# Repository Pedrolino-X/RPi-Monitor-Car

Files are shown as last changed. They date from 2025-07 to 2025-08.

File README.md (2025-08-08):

# RPi Monitor Car / 管道巡检车

<p align="center">
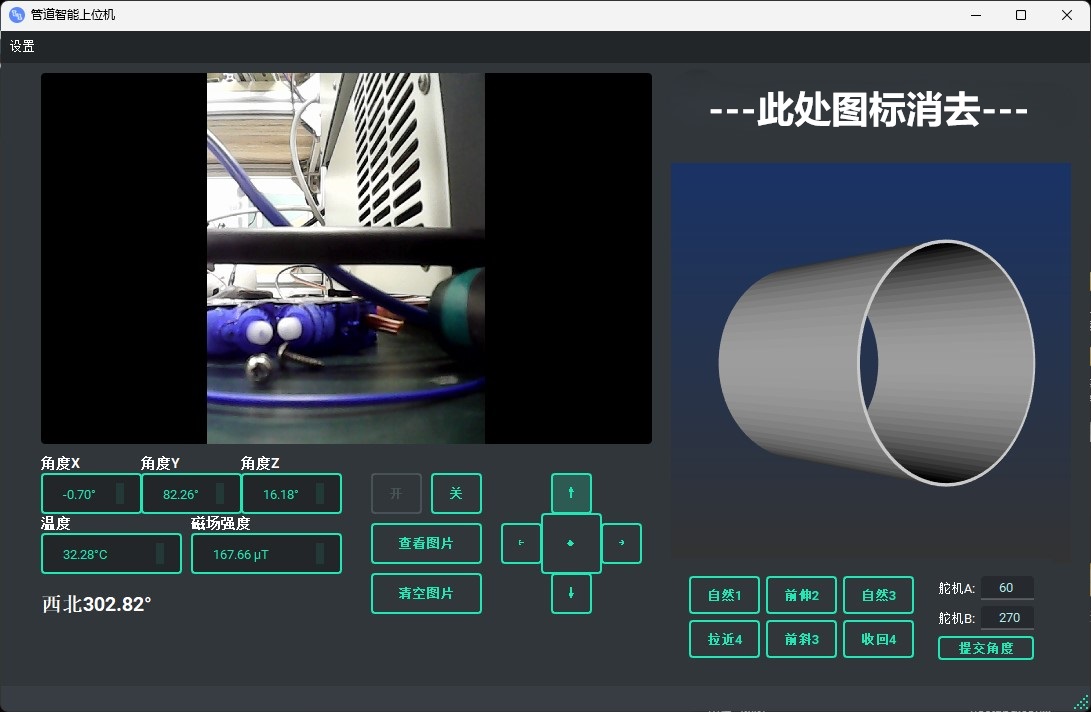
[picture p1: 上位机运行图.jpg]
PC Client Interface
  
</p>

<p align="center">
  
  
  
</p>

A inspection car system based on Raspberry Pi 5 and a PC client, designed for remote visual inspection in narrow environments like pipelines.

一个基于树莓派5和PC上位机的巡检车系统，旨在实现对管道等狭窄环境的远程可视化巡检。

---

## 核心功能 / Core Features

**车载端 (Raspberry Pi):**
- **🚗 运动控制 (Motion Control):** 控制直流电机，实现前进、后退及转向。
- **🧭 姿态感知 (Attitude Sensing):** 集成IMU（JY901S），实时获取并回传车辆的三轴姿态角、温度等数据。
- **📹 视觉采集 (Visual Capture):** 通过摄像头捕捉高清实时视频流，并支持远程拍照。
- **🦾 简易机械臂 (Simple Robotic Arm):** 控制两个舵机，执行预设的抓取或调整动作。
- **📡 无线通信 (Wireless Communication):** 内置TCP服务器，稳定接收PC指令并回传数据。车载端支持AP（热点）模式用于常规操作，以及STA（客户端）模式用于开发调试。

**上位机 (PC Client):**
- **🖥️ 图形化界面 (GUI):** 基于PyQt构建，提供直观的控制与数据显示界面。
- **🕹️ 远程遥控 (Remote Control):** 支持键盘 (W/A/S/D) 和UI按钮两种方式控制小车运动。
- **📊 实时监控 (Real-time Monitoring):**
  - 左侧窗口实时显示摄像头回传的视频流。
  - 中间仪表盘动态可视化展示车辆的俯仰、横滚、偏航角度。
  - 右侧窗口通过VTK加载并显示3D模型。
- **📂 自动文件同步 (Auto File Sync):** 后台服务通过SCP协议自动下载车载端拍摄的照片到本地，方便查看和管理。

---

## 技术栈 / Tech Stack

- **Hardware:** Raspberry Pi 5, JY901S IMU, TB6612FNG Motor Driver, SG90 Servos, Pi Camera
- **Raspberry Pi Software:** Python, OpenCV, RPi.GPIO, Pyserial, Socket
- **PC Client Software:** Python, PyQt5, PyOpenGL, VTK, Paramiko (for SCP)
- **Communication Protocol:** TCP/IP, SCP

---

## 快速开始 / Getting Started

### 1. 树莓派端设置 / Raspberry Pi Setup

1.  **硬件连接 (Hardware Connection):**
    - 根据 `交接文档.md` 内的接线图，连接好电机、舵机、IMU和摄像头。
    - 使用能提供5V/5A的稳定电源为树莓派供电。

2.  **软件部署 (Software Deployment):**
    - **(推荐)** 烧录项目提供的预配置系统镜像 (`.pmfx` 文件，不包含在仓库中)。
    - **(手动)** 或在一个干净的Raspberry Pi OS上，根据 `交接文档.md` 的指南安装所有依赖，并将 `树莓派端代码/` 目录下的文件部署到树莓派。

3.  **启动服务 (Start Service):**
    - 树莓派开机后，系统将默认创建一个名为 `MyPiAP` 的Wi-Fi热点 (密码: `raspberry`)。
    - 服务会自动运行。如果需要手动启动，请在代码目录下执行 `python3 server.py`。

### 2. 上位机端设置 / PC Client Setup

1.  **环境准备 (Environment):**
    - 确保你的PC上安装了 Python 3.7+。
    - 克隆或下载本仓库代码。

2.  **安装依赖 (Install Dependencies):**
    - 打开命令行，进入 `上位机软件代码/` 目录。
    - (推荐) 创建并激活虚拟环境。
    - 运行以下命令安装所有必需的库：
      ```bash
      pip install -r requirements.txt
      ```

3.  **运行程序 (Run Application):**
    - **(开发模式)** 直接运行主程序：
      ```bash
      python main.py
      ```
    - **(可执行文件)** 或直接运行 `上位机软件代码/dist/` 目录下的 `.exe` 文件。

---

## 操作流程 / Usage

1.  **连接网络:** 将你的PC连接到树莓派创建的 `MyPiAP` Wi-Fi网络。
2.  **启动上位机:** 运行PC端的应用程序。
3.  **建立连接:** 在上位机界面点击 **"开"** 按钮。
4.  **开始控制:**
    - 使用 **W, A, S, D** 或界面按钮控制移动。
    - 点击 **"◈"** 按钮或者**P**拍照。
    - 点击 **"查看图片"** 按钮，会自动打开存放同步照片的文件夹。
    - 使用右下角的按钮控制机械臂。
5.  **断开连接:** 点击 **"关"** 按钮结束。

---

## 协议 / License

This project is licensed under the MIT License. See the `LICENSE` file for details.

本项目采用 MIT 协议。详情见 `LICENSE` 文件。

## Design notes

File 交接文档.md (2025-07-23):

# 管道智能巡检车项目交接文档

## 1. 项目概述

本项目是一个基于树莓派5的智能巡检车系统，由**树莓派车载端**和**PC上位机控制端**两部分组成，通过Wi-Fi网络进行无线通信。该系统旨在实现对管道等狭窄环境的远程可视化巡检。

*   **车载端核心功能**:
    *   **运动控制**: 驱动直流电机实现前进、后退、左转、右转。
    *   **姿态感知**: 通过JY901S陀螺仪/IMU传感器实时获取车辆的姿态角、温度、磁场等数据。
    *   **视觉采集**: 使用摄像头捕捉实时视频流。
    *   **机械臂操作**: 控制两个舵机组成的简易机械臂执行预设动作。
    *   **通信服务**: 运行一个TCP服务器，接收上位机指令并回传传感器数据。

*   **上位机核心功能**:
    *   **远程遥控**: 提供图形化界面，通过键盘或UI按钮发送控制指令。
    *   **实时监控**: 显示来自车载摄像头的实时视频流。
    *   **数据可视化**: 以仪表盘形式展示车辆的姿态数据，辅以3D模型呈现。
    *   **文件管理**: 自动同步并管理车载端拍摄的照片。

## 2. 系统架构

```mermaid
graph TD
    subgraph "PC 上位机"
        UI["控制界面 (main.py)"]
        TCP_Client["TCP客户端 (tcpsend.py)"]
        Video_Client["视频流接收 (camera.py)"]
        SCP_Client["文件下载 (SCPDownload.py)"]
        PC_Photos["照片存储 (PC)"]
    end
  
    subgraph "树莓派5巡检车"
        Main_Server["主服务 (server.py)"]
        Hardware_Control["电机/舵机硬件控制 (RPi.GPIO)"]
        Video_Streamer["视频流服务 (OpenCV Port:8081)"]
        IMU_Reader["陀螺仪数据采集 (gyro.py)"]
        TCP_Server["TCP命令服务器 (socket Port:8082)"]
        SSH_Service["系统SSH/SCP服务"]
        RPi_Photos["照片存储 (RPi)"]
    end

    UI -- "发送控制指令 (w, a, s, d, servo...)" --> TCP_Client;
    TCP_Client -- "TCP/IP" --> TCP_Server;
    TCP_Server -- "解析指令" --> Hardware_Control;
  
    Video_Streamer -- "发送视频帧" --> Video_Client;
    Video_Client -- "解码并显示" --> UI;
  
    IMU_Reader -- "获取数据" --> Main_Server;
    Main_Server -- "打包数据" --> TCP_Server;
    TCP_Server -- "回传传感器数据 (angleX, angleY...)" --> UI;
  
    TCP_Server -- "调用拍照函数" --> Video_Streamer;
    Video_Streamer -- "保存照片" --> RPi_Photos;
  
    SCP_Client -- "轮询请求新文件" --> SSH_Service;
    SSH_Service -- "通过SCP传输" --> RPi_Photos;
    RPi_Photos -- "传输到PC" --> SCP_Client;
    SCP_Client -- "保存照片" --> PC_Photos;
```

## 3. 树莓派端 (车载端) 详细部署指南

### 3.1 硬件物料清单 (BOM)

| 类别 | 名称 | 数量 | 备注 |
| :--- | :--- | :--- | :--- |
| **核心** | 树莓派 5 | 1 | |
| | 32GB / 64GB MicroSD 卡（推荐64G） | 1 | |
| | 移动电源 | 1 | 需提供稳定5V/5A供电 |
| **视觉** | 树莓派摄像头模组 | 1 | CSI接口或USB接口均可 |
| **传感** | 维特智能 JY901S 陀螺仪 | 1 | UART通信 |
| **驱动** | TB6612FNG 电机驱动板 (或类似) | 1 | |
| | 直流减速电机 | 2 | |
| | SG90/MG90A 舵机 (推荐MG90A) | 2 | 组成机械臂 |
| **其他** | 杜邦线、车架、轮子等 | 若干 | |

### 3.2 硬件接线配置

**警告：接线前请确保树莓派已断电。所有GPIO引脚编号均基于BCM模式。**

| 组件 | 组件引脚 | 连接至树莓派GPIO引脚 | 功能说明 |
| :--- | :--- | :--- | :--- |
| **电机驱动板** | STBY | 3.3V | 驱动板使能 |
| | PWMA | GPIO 13 (PWM0) | 左轮电机PWM调速 |
| | AIN1 | GPIO 19 | 左轮电机方向控制1 |
| | AIN2 | GPIO 26 | 左轮电机方向控制2 |
| | PWMB | GPIO 16 (PWM0) | 右轮电机PWM调速 |
| | BIN1 | GPIO 20 | 右轮电机方向控制1 |
| | BIN2 | GPIO 21 | 右轮电机方向控制2 |
| | GND | GND | 共地 |
| | VCC/VM | - | 接外部电源正极 (如移动电源12V) |
| **舵机A** | 信号线 (橙色) | GPIO 17 (PWM1) | 舵机A PWM控制 |
| | VCC (红色) | 5V |按照产品使用3.3V/5V |
| | GND (棕色) | GND | 注意共地|
| **舵机B** | 信号线 (橙色) | GPIO 22 | 舵机B PWM控制 |
| | VCC (红色) | 5V | 按照产品使用3.3V/5V|
| | GND (棕色) | GND | 注意共地|
| **JY901S陀螺仪**| VCC | 3.3V | |
| | GND | GND | 注意共地|
| | TX | **GPIO 15 (RXD0)** | 树莓派的接收端 |
| | RX | **GPIO 14 (TXD0)** | 树莓派的发送端 |
| **摄像头** | - | CSI接口 / USB接口 | 视频采集 |

### 3.3 系统镜像部署 (首选方案)

此方案为最快捷的方式，包含了所有配置好的环境和代码。

1.  **下载工具**: 在PC上准备好磁盘镜像烧录工具 (如 `DiskGenius`, `Raspberry Pi Imager` 等)。
2.  **准备镜像**: 找到项目文件中的 `RPiCC_MonitorCar_SystemImage_Final_20250714_Archived.pmfx` (此文件不包含在Git仓库中)。
3.  **烧录镜像**:
    *   使用烧录工具，将 `.pmfx` 镜像文件恢复到 MicroSD 卡。
4.  **启动**: 将烧录好的内存卡插入树莓派5，连接好所有硬件并通电启动。

### 3.4 手动环境搭建 (高级/备用方案)
如果您想从一个全新的、纯净的Raspberry Pi OS系统开始，请按以下步骤操作：

1.  **烧录系统**: 使用 Raspberry Pi Imager 烧录最新的 "Raspberry Pi OS with desktop (64-bit)"。
2.  **基础配置**:
    *   通过外接显示器和键鼠完成首次启动向导。
    *   在终端中，启用 **SSH**, **VNC**, **UART (Serial Port)**, 和 **Legacy Camera Support** (如果使用旧款摄像头)。可通过 `sudo raspi-config` 命令进行设置。
    *   开启UART (Serial Port)时，若提示是否用于 **Serial Console**，请选择“否”。
3.  **安装系统依赖**:
    ```bash
    sudo apt-get update
    sudo apt-get install -y python3-pip python3-opencv libatlas-base-dev
	sudo pip3 install RPi.GPIO --upgrade
    ```
4.  **安装Python库**:
    ```bash
    pip3 install pyserial numpy
    ```
5.  **部署代码**: 将 `树莓派端代码` 目录下的所有文件和子目录，上传到树莓派的某一工作目录，例如 `/home/pi/rpi_server/`。

### 3.5 网络配置与模式切换

系统内置了通过 `nmcli` (NetworkManager命令行工具) 控制的两种网络模式。

#### 3.5.1 AP模式 (默认热点模式)

*   **用途**: 无需外部路由器，方便户外或现场快速部署。
*   **状态**: 系统镜像烧录后首次启动即进入此模式。
*   **网络详情**:
    *   **Wi-Fi名称 (SSID)**: `MyPiAP`
    *   **密码**: `raspberry`
    *   **树莓派IP**: `192.168.12.1`
*   **切换到此模式**:
    ```bash
    # 在树莓派终端执行
    sudo ./start-ap.sh
    ```

#### 3.5.2 STA模式 (Wi-Fi客户端模式)

*   **用途**: 连接到现有Wi-Fi网络，方便远程开发、调试和访问互联网。
*   **配置方法**:
    1.  在AP模式下，使用SSH连接到树莓派 (`ssh pi@192.168.12.1`)。
    2.  在SSH终端中，编辑 `start-wifi.sh` 文件：`nano ./start-wifi.sh`。
    3.  找到 `nmcli device wifi connect ...` 这一行，将其修改为您的Wi-Fi信息。
    4.  执行切换:
        ```bash
        sudo ./start-wifi.sh
        ```
        树莓派会断开AP，连接到您指定的Wi-Fi。您需要到路由器管理页面或使用网络扫描工具查找树莓派的新IP地址。

## 4. 上位机端 (PC控制端) 详细部署指南

### 4.1 直接运行可执行文件 (首选方案)

1.  在Windows电脑上，找到 `上位机软件代码/dist/` 目录。
2.  双击运行 `main.exe` 或 `上位机.exe` 文件即可启动应用程序。无需安装任何额外软件。

### 4.2 开发环境搭建 (用于二次开发)

1.  **安装Python**: 访问 [Python官网](https://www.python.org/downloads/) 下载并安装Python 3.7+ 版本。**安装时务必勾选 "Add Python to PATH"**。
2.  **拷贝代码**: 将 `上位机软件代码` 目录下的所有源文件拷贝到你的项目目录中。
3.  **创建并激活虚拟环境** (强烈推荐):
    ```bash
    # 在项目目录下打开CMD或PowerShell
    python -m venv venv
    .\venv\Scripts\activate
    ```
4.  **安装依赖**:
    ```bash
    pip install -r requirements.txt
    ```
5.  **运行程序**:
    ```bash
    python main.py
    ```

### 4.3 重新打包为.exe文件

如果修改了代码，需要重新生成 `.exe` 文件：
1.  确保已在虚拟环境中。
2.  安装 PyInstaller: `pip install pyinstaller`。
3.  执行打包命令 (使用 `.spec` 文件可以保留如图标、数据文件等配置):
    ```bash
    pyinstaller 上位机.spec
    ```
4.  打包完成后，新的可执行文件会出现在 `dist/` 目录下。

## 5. 完整操作流程 (从零开始)

1.  **树莓派准备**: 按照 **3.2** 接好所有硬件，然后按照 **3.3** 烧录系统镜像并启动树莓派。
2.  **网络连接**: 在PC上搜索Wi-Fi，连接到 `MyPiAP` (密码: `raspberry`)。
3.  **启动上位机**: 在PC上，运行 `dist` 目录下的可执行文件。
4.  **建立通信**: 在上位机界面，点击 **"开"** 按钮。
    *   如果一切正常，视频画面会出现在左侧，中间的数据仪表盘开始显示数据，右侧的3D模型会加载出来。
5.  **进行遥控**:
    *   **移动**: 使用界面上的方向按钮或键盘 **W, A, S, D**。
    *   **拍照**: 点击界面中心的 **"◈"** 按钮。照片会保存在树莓派上，并由后台服务自动同步到PC的 `Camera_Photos` 目录。
    *   **查看照片**: 点击 **"查看图片"** 按钮，会打开上述照片文件夹。
    *   **机械臂**: 使用右下角的预设按钮或在输入框中填入自定义角度后点击"提交角度"来控制舵机。
6.  **结束操作**: 点击 **"关"** 按钮断开连接，然后关闭上位机程序。

## 6. 代码与文件结构详解

### 6.1 树莓派端

| 文件/目录 | 描述 |
| :--- | :--- |
| `server.py` | **核心服务**。监听8081端口提供视频流，监听8082端口处理TCP指令。包含电机、舵机控制逻辑，并周期性调用 `gyro.py` 获取数据。 |
| `gyro.py` | 陀螺仪数据接口。封装了 `JY901S` 库，提供 `get_gyro_data()` 函数。 |
| `Python-WitProtocol/`| 陀螺仪(维特智能)官方Python SDK。 |
| `start-ap.sh` | 切换到AP模式的脚本。 |
| `start-wifi.sh` | 切换到STA模式的脚本。 |
| `enable-autostart.sh`| 启用服务自启动。 |
| `disable-autostart.sh`| 禁用服务自启动。 |

### 6.2 上位机端

| 文件/目录 | 描述 |
| :--- | :--- |
| `main.py` | **主程序入口**。初始化PyQt界面，绑定所有按钮事件，创建并启动各个功能线程。 |
| `UI_camera.py` | 由 `UI_camera.ui` 生成的UI类，**不要手动修改此文件**。 |
| `tcpsend.py` | **TCP客户端**。负责连接到树莓派的8082端口，发送控制指令并接收回传数据。 |
| `camera.py` | **视频流客户端**。连接到树莓派的8081端口，循环接收视频帧数据并解码。 |
| `SCPDownload.py` | **文件同步服务**。通过SSH和SCP协议，定期将树莓派上的新照片下载到本地。 |
| `model1.stl` | **3D模型文件**，由VTK库在界面右侧加载并渲染。 |
| `requirements.txt` | Python依赖列表，是复现开发环境的关键。 |

## 7. 故障排查 (Troubleshooting)

*   **上位机无法连接?**
    1.  确认PC是否已连接到正确的Wi-Fi (`MyPiAP`)。
    2.  在PC的CMD中 `ping 192.168.12.1`，检查网络是否通畅。
    3.  检查PC的防火墙是否阻止了应用程序的网络访问。

*   **视频无画面但能控制?**
    1.  检查树莓派摄像头是否已正确连接并被系统识别。
    2.  SSH登录树莓派，运行 `ls /dev/video*`，看是否有 `video0` 等设备。
    3.  在树莓派终端手动运行 `python3 server.py`，观察是否有关于摄像头或端口8081的报错。

*   **小车无法移动?**
    1.  检查电机驱动板的接线是否正确，特别是**电源和GND**，**共地**非常重要。
    2.  确认移动电源电量充足，能提供足够电流。
    3.  SSH登录树莓派，运行 `server.py` 并观察是否有 `RPi.GPIO` 相关的报错。

*   **陀螺仪无数据?**
    1.  检查JY901S的UART接线（TX到RX，RX到TX）是否正确，**共地**非常重要。
    2.  确认树莓派的UART功能已在 `raspi-config` 中启用。
    3.  手动运行 `server.py`，观察是否有 `pyserial` 或端口 `/dev/ttyAMA0` 相关的报错。

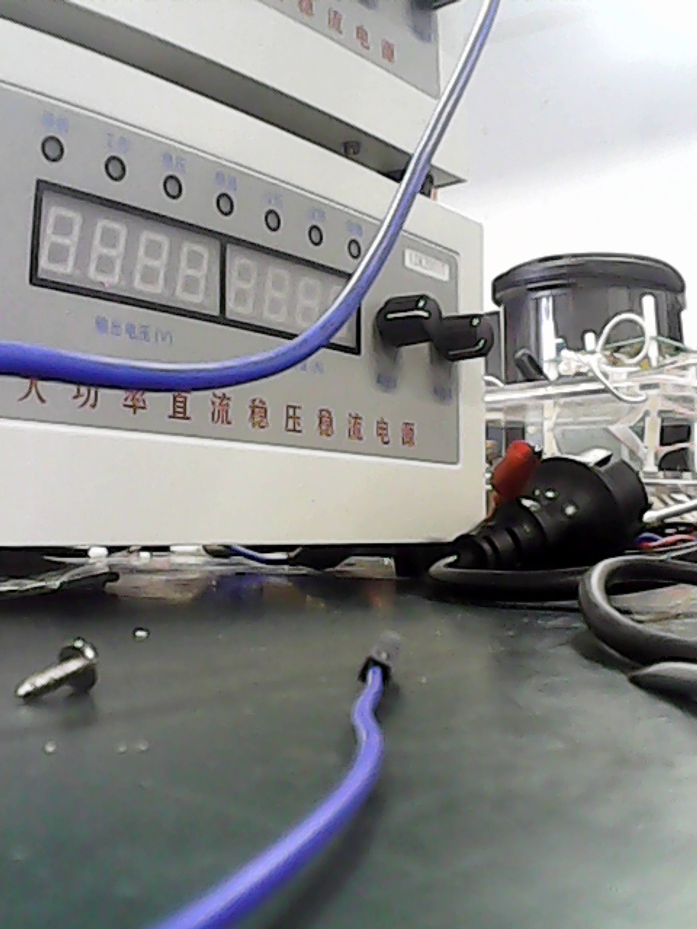
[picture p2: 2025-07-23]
上位机软件代码/Camera_Photos/capture_2025-07-13_23-59-16.jpg

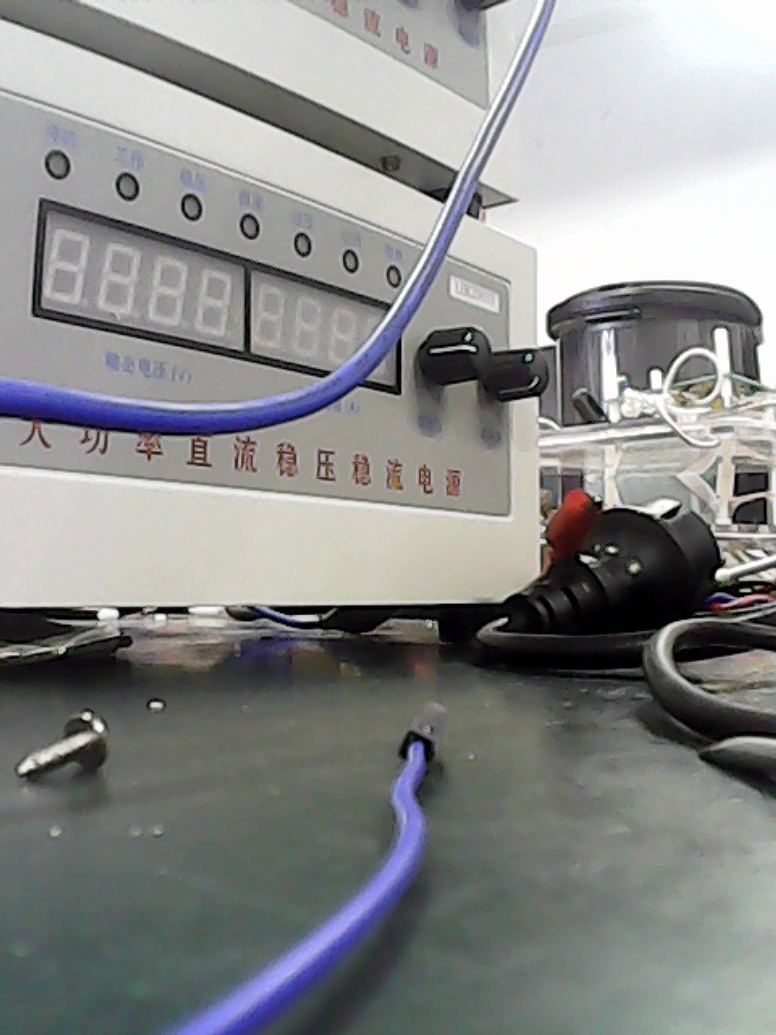
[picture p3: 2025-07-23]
上位机软件代码/Camera_Photos/capture_2025-07-13_23-57-38.jpg

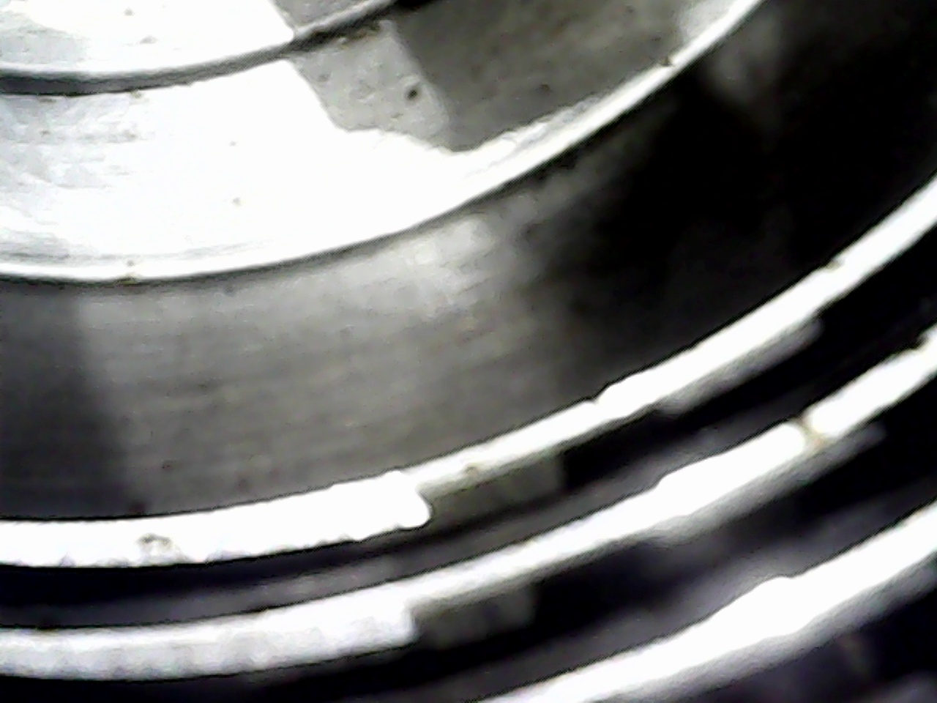
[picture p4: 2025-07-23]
上位机软件代码/Camera_Photos/capture_2024-11-12_17-41-52.jpg

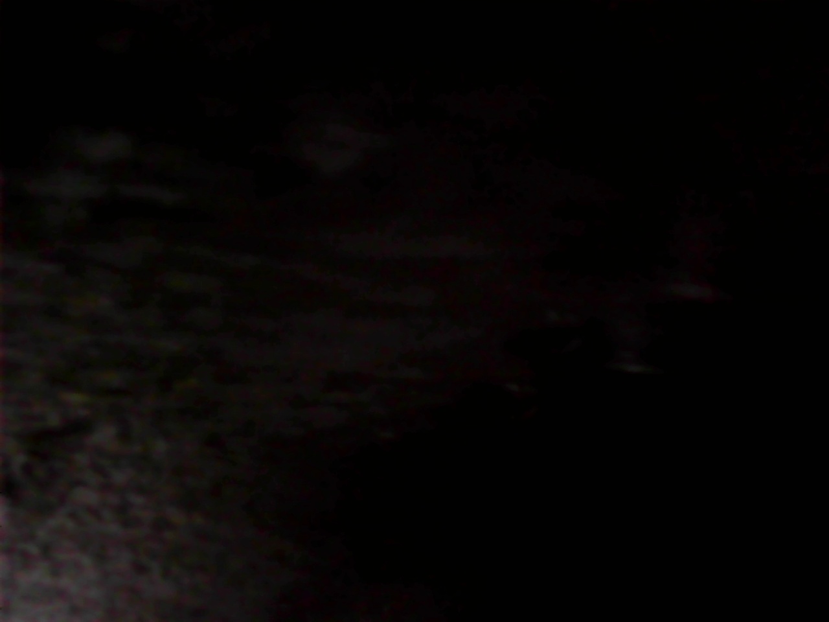
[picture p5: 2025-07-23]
上位机软件代码/Camera_Photos/capture_2024-11-12_17-10-20.jpg

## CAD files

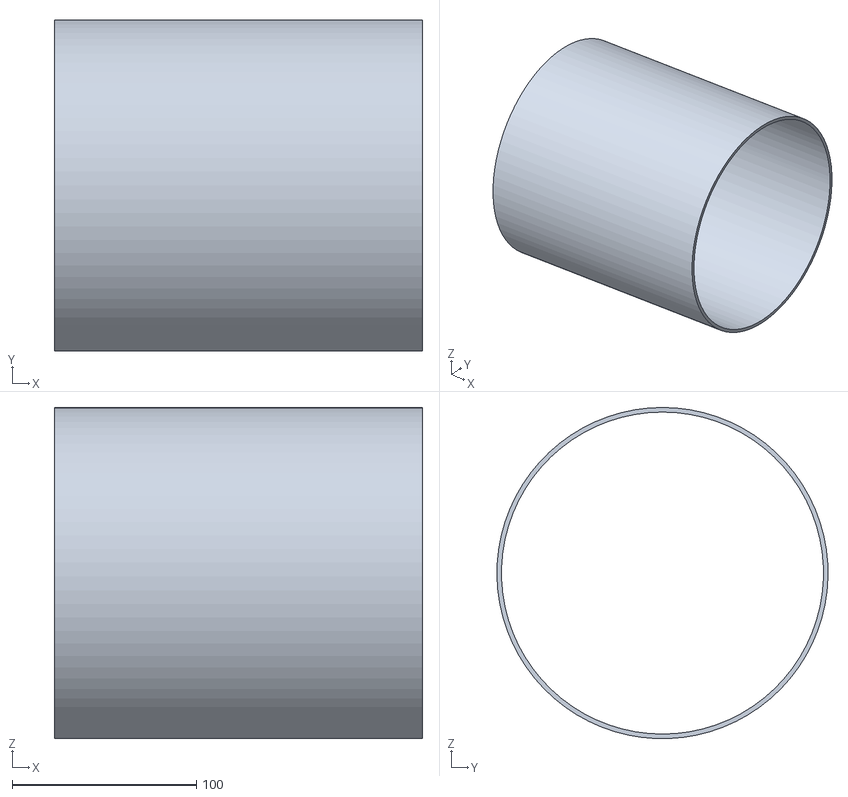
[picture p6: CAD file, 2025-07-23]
上位机软件代码/model1.stl
200.0 x 180.0 x 179.9

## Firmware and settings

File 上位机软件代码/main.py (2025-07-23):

import base64
import shutil
import sys
import os
import threading
import math
from datetime import datetime

from PyQt5.QtWidgets import QMainWindow, QApplication, QMessageBox
from PyQt5.QtGui import QImage, QPixmap
from PyQt5.QtCore import Qt, QThread, pyqtSignal, pyqtSlot
from PyQt5 import uic, QtGui, QtCore
from UI_camera import Ui_MainWindow
from qt_material import apply_stylesheet
import cv2
from lib.share import SI
from camera import NetworkCamera
from tcpsend import TCPClient
from SCPDownload import sync_folder
from memory_pic import logo_ico,saishi_png,gongsi_png
import base64
import vtk
from vtk.qt.QVTKRenderWindowInteractor import QVTKRenderWindowInteractor

def resource_path(relative_path):
    """ Get absolute path to resource, works for dev and for PyInstaller """
    try:
        # PyInstaller creates a temp folder and stores path in _MEIPASS
        base_path = sys._MEIPASS
    except Exception:
        base_path = os.path.abspath(".")

    return os.path.join(base_path, relative_path)

class StlWorker(QtCore.QThread):
    finished = QtCore.pyqtSignal()

    def __init__(self, ren, parent=None):
        super().__init__(parent)
        self.ren = ren

    def run(self):
        stlreader = vtk.vtkSTLReader()
        stlreader.SetFileName(resource_path(".\model1.stl"))
        mapper = vtk.vtkPolyDataMapper()
        mapper.SetInputConnection(stlreader.GetOutputPort())
        mapper.SetScalarVisibility(0)
        actor = vtk.vtkActor()
        actor.SetMapper(mapper)
        self.ren.AddActor(actor)
        self.ren.ResetCamera()
        self.finished.emit()


class IP_Config:
    def __init__(self):
        print("IP配置窗口")
        self.ui = uic.loadUi("ip_config.ui")

class CameraWorker(QThread):
    new_frame = pyqtSignal(object)

    def __init__(self, network_camera, parent=None):
        super().__init__(parent)
        self.network_camera = network_camera
        self.running = False

    def run(self):
        self.running = True
        while self.running:
            if self.network_camera.is_connected():
                try:
                    frame = self.network_camera.get_frame()
                    if frame is not None:
                        self.new_frame.emit(frame)
                except Exception as e:
                    print(f"Exception in CameraWorker: {e}")
            else:
                self.msleep(100)

    def stop(self):
        self.running = False
        self.wait()

class MainWindow(QMainWindow, Ui_MainWindow):
    update_angle_signal = pyqtSignal(dict)  # 定义信号

    def __init__(self, parent=None):
        super(MainWindow, self).__init__(parent)
        # UI界面
        self.camera_worker = None
        self.ctrl_message = None
        self.setupUi(self)
        # self.CAM_NUM = 0
        # self.cap = cv2.VideoCapture()
        self.network_camera = NetworkCamera('192.168.12.1', 8081)
        # self.network_camera = NetworkCamera("http://192.168.4.1:81/stream")
        self.tcp_client = TCPClient('192.168.12.1', 8082)
        self.key_pressed = {}  # 用于跟踪按键状态
        self.button_pressed = set()  # 用于跟踪按钮状态
        self.key_timers = {}  # 用于跟踪按键的定时器
        self.background()

        # --- VTK and STL Model Loading Setup ---
        self.vtkWidget = QVTKRenderWindowInteractor(self.centralwidget)
        self.verticalLayout.addWidget(self.vtkWidget)
        self.ren = vtk.vtkRenderer()
        self.ren.SetBackground(1.0, 1.0, 1.0)
        self.ren.SetBackground2(0.1, 0.2, 0.4)
        self.ren.SetGradientBackground(1)
        self.vtkWidget.GetRenderWindow().AddRenderer(self.ren)
        self.iren = self.vtkWidget.GetRenderWindow().GetInteractor()
        style = vtk.vtkInteractorStyleTrackballCamera()
        self.iren.SetInteractorStyle(style)

        self.stl_worker = StlWorker(self.ren)
        self.stl_worker.finished.connect(self.on_stl_loaded)
        self.stl_worker.start()
        # --- End of VTK Setup ---

        decoded_just = QtCore.QByteArray(base64.b64decode(gongsi_png))
        jpg_just = QtGui.QPixmap()
        jpg_just.loadFromData(decoded_just)
        jpg_just = jpg_just.scaled(
            self.label_just.width()*0.81, self.label_just.height()*0.81, Qt.KeepAspectRatio, Qt.SmoothTransformation)
        self.label_just.setPixmap(jpg_just)

        decoded_shdq = QtCore.QByteArray(base64.b64decode(saishi_png))
        jpg_shdq = QtGui.QPixmap()
        jpg_shdq.loadFromData(decoded_shdq)
        jpg_shdq = jpg_shdq.scaled(
            self.label_shdq.width()*1.0, self.label_shdq.height()*1.0, Qt.KeepAspectRatio, Qt.SmoothTransformation)
        self.label_shdq.setPixmap(jpg_shdq)

        # 为SCP同步创建一个事件
        self.scp_stop_event = threading.Event()
        self.scp_thread = None

        # 启动接收角度数据的线程
        self.start_receiving_data()
        self.update_angle_signal.connect(self.update_display)  # 连接信号和槽
        self.setFixedSize(self.width(), self.height())

    def on_stl_loaded(self):
        self.ren.SetBackground(0.2, 0.2, 0.2)
        camera = self.ren.GetActiveCamera()
        camera.Zoom(1)
        self.iren.SetDesiredUpdateRate(10.0)
        self.vtkWidget.show()
        self.iren.Initialize()

    def ip_set(self):
        SI.mainWin = IP_Config()
        SI.mainWin.ui.show()

    def background(self):
        # 文件选择按钮
        self.camera_on_pushButton.clicked.connect(self.open_connections)
        self.camera_off_pushButton.clicked.connect(self.close_connections)

        self.camera_on_pushButton.setEnabled(True)
        # 初始状态不能关闭摄像头和TCP连接
        self.camera_off_pushButton.setEnabled(False)

        # 目录配置窗口
        self.action_ipconfig.triggered.connect(self.ip_set)

        self.album_pushButton.clicked.connect(self.open_folder)
        self.album_clear_pushButton.clicked.connect(self.clear_album)
        # 按钮控制发送信息
        self.ctrl_up_pushButton.pressed.connect(lambda: self.handle_button_press('w', self.ctrl_up_pushButton))
        self.ctrl_up_pushButton.released.connect(lambda: self.handle_button_release('stop', self.ctrl_up_pushButton))
        self.ctrl_down_pushButton.pressed.connect(lambda: self.handle_button_press('s', self.ctrl_down_pushButton))
        self.ctrl_down_pushButton.released.connect(lambda: self.handle_button_release('stop', self.ctrl_down_pushButton))
        self.ctrl_left_pushButton.pressed.connect(lambda: self.handle_button_press('a', self.ctrl_left_pushButton))
        self.ctrl_left_pushButton.released.connect(lambda: self.handle_button_release('stop', self.ctrl_left_pushButton))
        self.ctrl_right_pushButton.pressed.connect(lambda: self.handle_button_press('d', self.ctrl_right_pushButton))
        self.ctrl_right_pushButton.released.connect(
            lambda: self.handle_button_release('stop', self.ctrl_right_pushButton))
        self.ctrl_shoot_pushButton.released.connect(lambda: self.send_message('p'))
        self.servo_100150_pushButton.pressed.connect(lambda: self.send_message('servoA:100,servoB:150'))
        self.servo_4090_pushButton.pressed.connect(lambda: self.send_message('servoA:40,servoB:90'))
        self.servo_90150_pushButton.pressed.connect(lambda: self.send_message('servoA:40,servoB:90'))
        self.servo_90150_pushButton_2.pressed.connect(lambda: self.send_message('servoM'))
        self.servo_90240_pushButton.pressed.connect(lambda: self.send_message('servoA:90,servoB:240'))
        self.servo_80160_pushButton.pressed.connect(lambda: self.send_message('servoA:80,servoB:160'))
        self.submit_custom_servo_pushButton.clicked.connect(self.send_custom_servo_angles)


    def send_custom_servo_angles(self):
        angle_a = self.servoA_lineEdit.text()
        angle_b = self.servoB_lineEdit.text()
        if angle_a and angle_b:
            try:
                # Validate that inputs are integers
                int(angle_a)
                int(angle_b)
                message = f"servoA:{angle_a},servoB:{angle_b}"
                self.send_message(message)
            except ValueError:
                QMessageBox.warning(self, "输入错误", "角度必须是有效的整数", QMessageBox.Ok)
        else:
            QMessageBox.warning(self, "输入错误", "请输入舵机A和舵机B的角度", QMessageBox.Ok)




    def handle_button_press(self, message, button):
        if button not in self.button_pressed:
            self.button_pressed.add(button)
            self.send_message(message)

    def handle_button_release(self, message, button):
        if button in self.button_pressed:
            self.button_pressed.remove(button)
            self.send_message(message)

    def keyPressEvent(self, event):
        if event.isAutoRepeat():
            return
        key = event.key()
        if key not in self.key_pressed or not self.key_pressed[key]:
            self.key_pressed[key] = True
            self.update_movement()

    def keyReleaseEvent(self, event):
        if event.isAutoRepeat():
            return
        key = event.key()
        if key in self.key_pressed and self.key_pressed[key]:
            self.key_pressed[key] = False
            self.update_movement()

    def capture_photo(self):
        frame = self.network_camera.get_frame()
        if frame is not None:
            # 获取当前日期和时间作为文件名
            timestamp = datetime.now().strftime("%Y%m%d_%H%M%S")
            file_path = f"./Camera_Photos/{timestamp}.jpg"

            # 确保目录存在
            os.makedirs(os.path.dirname(file_path), exist_ok=True)

            # 保存照片
            cv2.imwrite(file_path, frame)
            print(f"照片已保存：{file_path}")
        else:
            print("无法获取视频帧，拍照失败。")

    def clear_photos(self):
        folder_path = "./Camera_Photos"
        if os.path.exists(folder_path):
            # 删除整个文件夹及其内容
            shutil.rmtree(folder_path)
            print("照片已清空。")

            # 重新创建空文件夹
            os.makedirs(folder_path, exist_ok=True)
        else:
            print("照片文件夹不存在，无需清空。")

    def update_movement(self):
        if self.key_pressed.get(Qt.Key_W) and self.key_pressed.get(Qt.Key_A):
            self.send_message('aw')
        elif self.key_pressed.get(Qt.Key_W) and self.key_pressed.get(Qt.Key_D):
            self.send_message('dw')
        elif self.key_pressed.get(Qt.Key_S) and self.key_pressed.get(Qt.Key_A):
            self.send_message('as')
        elif self.key_pressed.get(Qt.Key_S) and self.key_pressed.get(Qt.Key_D):
            self.send_message('ds')
        elif self.key_pressed.get(Qt.Key_W):
            self.send_message('w')
        elif self.key_pressed.get(Qt.Key_S):
            self.send_message('s')
        elif self.key_pressed.get(Qt.Key_A):
            self.send_message('a')
        elif self.key_pressed.get(Qt.Key_D):
            self.send_message('d')
        elif self.key_pressed.get(Qt.Key_P):
            self.send_message('p')
        elif self.key_pressed.get(Qt.Key_Q):
            self.send_message('q')
        elif self.key_pressed.get(Qt.Key_J):
            self.send_message('servoA:130,servoB:130')
        elif self.key_pressed.get(Qt.Key_K):
            self.send_message('servoA:40,servoB:40')
        else:
            self.send_message('stop')

    def open_folder(self):
        folder_path = r'.\Camera_Photos'  # 固定文件夹路径
        os.startfile(folder_path)

    def clear_album(self):
        try:
            # 发送 "clear" 的 TCP 消息
            self.send_message('clear')

            # 删除 .\Camera_Photos 文件夹下的所有文件
            folder_path = r'.\Camera_Photos'
            for filename in os.listdir(folder_path):
                file_path = os.path.join(folder_path, filename)
                if os.path.isfile(file_path):
                    os.remove(file_path)
            print("Album cleared and 'clear' message sent.")
        except Exception as e:
            print(f"Error clearing album: {str(e)}")
            QMessageBox.information(self, "错误", str(e), QMessageBox.Ok)

    # 打开相机和TCP连接
    def open_connections(self):

        try:
            self.network_camera.connect()
            self.tcp_client.connect()
            if not self.network_camera.is_connected():
                QMessageBox.information(self, "警告", "无法连接到网络摄像头", QMessageBox.Ok)
            elif not self.tcp_client.is_connected():
                QMessageBox.information(self, "警告", "无法连接到TCP服务器", QMessageBox.Ok)
            else:
                self.textBrowser_angleX.setText(f"-0.70°")
                self.textBrowser_angleY.setText(f"82.26°")
                self.textBrowser_angleZ.setText(f"16.18°")
                self.textBrowser_temperature.setText(f"32.28°C")
                self.textBrowser_magneticfield.setText(f"167.66 µT")
                self.label_direction.setText(f"西北302.82° ")
                # 幕布可以播放
                self.label.setEnabled(True)
                # 打开摄像头按钮不能点击
                self.camera_on_pushButton.setEnabled(False)
                # 关闭摄像头按钮可以点击
                self.camera_off_pushButton.setEnabled(True)
                
                self.camera_worker = CameraWorker(self.network_camera)
                self.camera_worker.new_frame.connect(self.update_camera_feed)
                self.camera_worker.start()

                self.send_message('servoA:30,servoB:30')
                print("Connections opened!")
                self.start_scp_sync()  # Start SCP sync when connections are open
                self.start_receiving_data()  # 启动接收数据的线程
        except Exception as e:
            QMessageBox.information(self, "错误", str(e), QMessageBox.Ok)

    # 关闭相机和TCP连接
    def close_connections(self):
        if self.camera_worker:
            self.camera_worker.stop()
        
        # Stop the SCP sync thread
        if self.scp_thread and self.scp_thread.is_alive():
            self.scp_stop_event.set()
            self.scp_thread.join(timeout=2) # Wait for the thread to finish

        self.label.setEnabled(False)
        self.network_camera.disconnect()
        self.tcp_client.close()
        self.camera_on_pushButton.setEnabled(True)
        self.camera_off_pushButton.setEnabled(False)
        self.label_direction.setText(f"等待连接... ")
        print("Connections closed!")

    # 发送消息
    def send_message(self, content=None):
        if self.tcp_client.is_connected():
            try:
                msg = content  # 按钮触发用于输入消息
                if msg:
                    print(f"Sending message: {msg}")  # 调试信息
                    threading.Thread(target=self.tcp_client.send_message, args=(msg,)).start()
            except Exception as e:
                print(f"Error sending message: {str(e)}")  # 调试信息
                QMessageBox.information(self, "错误", str(e), QMessageBox.Ok)
        else:
            print("TCP connection is not open.")  # 调试信息
            # QMessageBox.information(self, "警告", "TCP连接未打开", QMessageBox.Ok)

    @pyqtSlot(object)
    def update_camera_feed(self, frame):
        try:
            cur_frame = cv2.cvtColor(frame, cv2.COLOR_BGR2RGB)
            height, width = cur_frame.shape[:2]
            pixmap = QImage(cur_frame, width, height, QImage.Format_RGB888)
            pixmap = QPixmap.fromImage(pixmap)
            ratio = max(width / self.label.width(), height / self.label.height())
            pixmap.setDevicePixelRatio(ratio)
            self.label.setAlignment(Qt.AlignCenter)
            self.label.setPixmap(pixmap)
        except Exception as e:
            print(f"Exception occurred while updating camera feed: {str(e)}")


    # 启动SCP同步线程
    def start_scp_sync(self):
        if self.scp_thread and self.scp_thread.is_alive():
            print("SCP thread is already running.")
            return

        self.scp_stop_event.clear()
        self.scp_thread = threading.Thread(
            target=sync_folder,
            args=(
                "/home/user0000/Desktop/Camera_Photos",  # 服务器上的文件夹路径
                ".\Camera_Photos",  # 本地文件夹路径
                '192.168.12.1',  # 服务器IP
                22,  # SSH端口号
                'user0000',  # SSH用户名
                '0000',  # SSH密码
                1,  # 同步间隔时间（秒）
                self.scp_stop_event # Pass the event to the function
            )
        )
        self.scp_thread.daemon = True
        self.scp_thread.start()
        print("SCP sync thread started.")

    # 启动接收角度数据的线程
    def start_receiving_data(self):
        if self.tcp_client.is_connected():
            receiving_thread = threading.Thread(target=self.receive_data)
            receiving_thread.daemon = True
            receiving_thread.start()

    # 接收并解析数据
    def receive_data(self):
        while self.tcp_client.is_connected():
            try:
                data = self.tcp_client.receive_data()
                if data:
                    # print(data)
                    datasets = self.parse_data(data)
                    if datasets:
                        print(
                            f"angleX: {datasets['angleX']}, angleY: {datasets['angleY']}, angleZ: {datasets['angleZ']}")
                        #self.update_angle_signal.emit(datasets)  # 发射信号
            except Exception as e:
                print(f"Error receiving data: {str(e)}")

    # 解析数据
    def parse_data(self, data):
        try:
            parts = data.split(',')
            datasets = {
                'angleX': float(parts[0].split(':')[1]),
                'angleY': float(parts[1].split(':')[1]),
                'angleZ': float(parts[2].split(':')[1]),
                'temperature': float(parts[3].split(':')[1]),
                'magX': float(parts[4].split(':')[1]),
                'magY': float(parts[5].split(':')[1]),
                'magZ': float(parts[6].split(':')[1])
            }
            return datasets
        except (IndexError, ValueError) as e:
            print(f"Error parsing data: {str(e)}")
            return None

    # 更新显示框
    @pyqtSlot(dict)
    def update_display(self, datasets):
        self.textBrowser_angleX.setText(f"{datasets['angleX']:.2f}°")
        self.textBrowser_angleY.setText(f"{datasets['angleY']:.2f}°")
        self.textBrowser_angleZ.setText(f"{datasets['angleZ']:.2f}°")
        self.textBrowser_temperature.setText(f"{datasets['temperature']:.2f}°C")

        # 计算磁场强度
        magX, magY, magZ = datasets['magX'], datasets['magY'], datasets['magZ']
        mag_strength = math.sqrt(magX ** 2 + magY ** 2 + magZ ** 2)
        self.textBrowser_magneticfield.setText(f"{mag_strength/100:.2f} µT")

        # 计算方向
        angleZ = datasets['angleZ']
        if angleZ < 0:
            angleZ += 360
        angleZ = 359 - angleZ
        directions = [
            (22, "北"), (67, "东北"), (112, "东"),
            (157, "东南"), (202, "南"), (247, "西南"),
            (292, "西"), (337, "西北"), (360, "北")
        ]
        direction_str = next(d for deg, d in directions if angleZ <= deg)
        self.label_direction.setText(f"{direction_str}  {angleZ:.2f}° ")


if __name__ == '__main__':
    QApplication.setHighDpiScaleFactorRoundingPolicy(Qt.HighDpiScaleFactorRoundingPolicy.PassThrough)
    QApplication.setAttribute(Qt.AA_EnableHighDpiScaling)
    QApplication.setAttribute(Qt.AA_UseHighDpiPixmaps)
    app = QApplication(sys.argv)
    main = MainWindow()
    apply_stylesheet(app, theme='dark_teal.xml')

    #方法三：把图片转化为base64
    Logo = QtGui.QPixmap()
    Logo.loadFromData(base64.b64decode(logo_ico))
    icon = QtGui.QIcon()
    icon.addPixmap(Logo, QtGui.QIcon.Normal, QtGui.QIcon.Off)
    main.setWindowIcon(icon)

    main.show()
    sys.exit(app.exec_())

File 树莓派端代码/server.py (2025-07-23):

import socket
import threading
import time
import os
import RPi.GPIO as GPIO
import cv2
import struct
import random
from gyro import get_gyro_data

# --- Motor Control ---
STBY = 27
PWMA = 13
AIN1 = 19
AIN2 = 26
PWMB = 16
BIN1 = 20
BIN2 = 21
hz = 500
speed = 0

def setup_motors():
    GPIO.setmode(GPIO.BCM)
    GPIO.setwarnings(False)
    GPIO.setup(PWMA, GPIO.OUT)
    GPIO.setup(AIN1, GPIO.OUT)
    GPIO.setup(AIN2, GPIO.OUT)
    GPIO.setup(PWMB, GPIO.OUT)
    GPIO.setup(BIN1, GPIO.OUT)
    GPIO.setup(BIN2, GPIO.OUT)
    GPIO.setup(STBY, GPIO.OUT)
    global pwma, pwmb
    pwma = GPIO.PWM(PWMA, hz)
    pwmb = GPIO.PWM(PWMB, hz)
    pwma.start(speed)
    pwmb.start(speed)
    GPIO.output(STBY, True)

def move_forward():
    GPIO.output(AIN1, False)
    GPIO.output(AIN2, True)
    pwma.ChangeDutyCycle(85)
    GPIO.output(BIN1, False)
    GPIO.output(BIN2, True)
    pwmb.ChangeDutyCycle(80)

def move_backward():
    GPIO.output(AIN1, True)
    GPIO.output(AIN2, False)
    pwma.ChangeDutyCycle(85)
    GPIO.output(BIN1, True)
    GPIO.output(BIN2, False)
    pwmb.ChangeDutyCycle(80)

def turn_left():
    GPIO.output(AIN1, False)
    GPIO.output(AIN2, True)
    pwma.ChangeDutyCycle(85)
    GPIO.output(BIN1, True)
    GPIO.output(BIN2, False)
    pwmb.ChangeDutyCycle(80)

def turn_right():
    GPIO.output(AIN1, True)
    GPIO.output(AIN2, False)
    pwma.ChangeDutyCycle(85)
    GPIO.output(BIN1, False)
    GPIO.output(BIN2, True)
    pwmb.ChangeDutyCycle(80)

def stop_movement():
    pwma.ChangeDutyCycle(0)
    pwmb.ChangeDutyCycle(0)

# --- Servo Control ---
servoA_pin = 17
servoB_pin = 22

def setup_servos():
    GPIO.setup(servoA_pin, GPIO.OUT, initial=False)
    GPIO.setup(servoB_pin, GPIO.OUT, initial=False)
    global sA, sB
    sA = GPIO.PWM(servoA_pin, 50)
    sB = GPIO.PWM(servoB_pin, 50)
    sA.start(0)
    sB.start(0)

def set_servo_angle(servo, angle):
    duty_cycle = 2.5 + angle / 180.0 * 10
    servo.ChangeDutyCycle(duty_cycle)
    time.sleep(0.1)
    servo.ChangeDutyCycle(0)



# --- Camera ---
class VideoStreamer:
    def __init__(self, host, port):
        self.host = host
        self.port = port
        self.server_socket = socket.socket(socket.AF_INET, socket.SOCK_STREAM)
        self.clients = []
        self.lock = threading.Lock()
        self.camera = cv2.VideoCapture(0)

    def start(self):
        self.server_socket.setsockopt(socket.SOL_SOCKET, socket.SO_REUSEADDR, 1)
        self.server_socket.bind((self.host, self.port))
        self.server_socket.listen(5)
        print(f"Video streamer listening on {self.host}:{self.port}")
        accept_thread = threading.Thread(target=self.accept_clients)
        accept_thread.daemon = True
        accept_thread.start()

    def accept_clients(self):
        while True:
            client_socket, address = self.server_socket.accept()
            print(f"Video client connected from {address}")
            with self.lock:
                self.clients.append(client_socket)
            stream_thread = threading.Thread(target=self.stream_video, args=(client_socket,))
            stream_thread.daemon = True
            stream_thread.start()

    def stream_video(self, client_socket):
        try:
            while True:
                ret, frame = self.camera.read()
                if not ret:
                    break
                frame = cv2.rotate(frame, cv2.ROTATE_90_CLOCKWISE)
                _, encoded_frame = cv2.imencode('.jpg', frame)
                frame_data = encoded_frame.tobytes()
                frame_size = struct.pack("!L", len(frame_data))
                client_socket.sendall(frame_size + frame_data)
                time.sleep(0.03) # Limit frame rate
        except (BrokenPipeError, ConnectionResetError):
            print("Video client disconnected.")
        finally:
            with self.lock:
                self.clients.remove(client_socket)
            client_socket.close()

    def capture_photo(self, path):
        ret, frame = self.camera.read()
        if ret:
            frame = cv2.rotate(frame, cv2.ROTATE_90_CLOCKWISE)
            cv2.imwrite(path, frame)
            print(f"Photo saved to {path}")

# --- Main Server ---
class CommandServer:
    def __init__(self, host, port, video_streamer):
        self.host = host
        self.port = port
        self.server_socket = socket.socket(socket.AF_INET, socket.SOCK_STREAM)
        self.clients = []
        self.lock = threading.Lock()
        self.video_streamer = video_streamer
        self.photo_dir = os.path.expanduser("~/Desktop/Camera_Photos")
        if not os.path.exists(self.photo_dir):
            os.makedirs(self.photo_dir)

    def handle_client(self, client_socket, address):
        print(f"Command client connected from {address}")
        with self.lock:
            self.clients.append(client_socket)

        try:
            while True:
                data = client_socket.recv(1024).decode('utf-8')
                if not data:
                    break
                print(f"Received command from {address}: {data}")
                self.process_command(data)
        except ConnectionResetError:
            print(f"Command client from {address} reset.")
        finally:
            with self.lock:
                self.clients.remove(client_socket)
            client_socket.close()
            print(f"Command client from {address} closed.")

    def process_command(self, command):
        if command == 'w':
            move_forward()
        elif command == 's':
            move_backward()
        elif command == 'a':
            turn_left()
        elif command == 'd':
            turn_right()
        elif command in ('wc', 'sc', 'ac', 'dc', 'stop'):
            stop_movement()
        elif command == 'p':
            timestamp = time.strftime("%Y-%m-%d_%H-%M-%S")
            photo_path = os.path.join(self.photo_dir, f"capture_{timestamp}.jpg")
            self.video_streamer.capture_photo(photo_path)
        elif command.startswith("IP:"):
            print(f"Client IP info: {command}")
        elif command.startswith("servoA:"):
            try:
                parts = command.split(',')
                angleA_str = parts[0].split(':')[1]
                angleB_str = parts[1].split(':')[1]
                angleA = int(angleA_str)
                angleB = int(angleB_str)
                print(f"Setting servoA to {angleA}, servoB to {angleB}")
                set_servo_angle(sA, angleA)
                set_servo_angle(sB, angleB)
            except (IndexError, ValueError) as e:
                print(f"Invalid servo command format. Error: {e}")
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

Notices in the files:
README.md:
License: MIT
